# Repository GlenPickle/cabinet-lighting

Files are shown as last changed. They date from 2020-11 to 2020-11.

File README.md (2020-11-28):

Arduino controlled cabinet lighting with a Nextion Enhanced 3.2 inch TFT Display

## Design Description:

The Nextion screen allows the user to interface with the lights. A leader Arduino Pro Micro listens for instructions from the Nextion Interface over serial, and sends these instructions to a follower Arduino Pro Micro. The Leader/Follower design is used to prevent Nextion signals being missed while calling the blocking functions to change the color and brightness of the lights.

## Limitations:
In order for a Nextion callback function or Wire receiveEvent to update variables, they must be declared globally. This software and its Makefiles were made to be compiled on Linux. Windows compilation may be possible, but has not been tested.

## Screen Images:  
### The home screen:
  
### The color selection screen:

### The sliders to update brightness and speed:

### The settings screen:

### The Clock update screen. This is also used to set the times to turn off and on automatically:
  

## Light Images:
### Solid color choices:








### Pulse Effect:

### Alternating Effect

### Snake Effect

### Rainbow Effect

### Dance Party Effect


## How To Recreate:
### Software:
#### Dependencies:
* [Nextion Arduino Library](https://nextion.tech/resources/download/libraries/)
* [FastLED Library](https://github.com/FastLED/FastLED/releases)
* arduino-mk

#### Steps:
1. Install dependencies
2. Change the variable NUM_LEDS in libraries/ledInterface/led_interface.h to the number of LEDs that you plan to use
3. Compile LED interface by running `make` in the led_interface directory
4. Compile Screen interface by running `make` in the screen_interface directory
5. Upload the resulting sketch files to the arduinos following these [instructions](https://www.dummies.com/computers/arduino/how-to-upload-a-sketch-to-an-arduino/)
6. Use the [Nextion Editor](https://nextion.tech/nextion-editor/) to compile the HMI file into a Nextion .tft file
7. Upload the .tft to the Nextion following these [instructions](https://nextion.tech/faq-items/using-nextion-microsd/)

### Hardware
#### Hardware List:
1. Two [Arduino Pro Micros](https://www.sparkfun.com/products/12640) (cheaper clones available on Amazon)
2. One [Nextion 3.2 inch Enhanced Display](https://nextion.tech/datasheets/nx4024k032/) (available on Amazon)
3. A Five volt power supply with sufficient amperage. 256 LEDs use 15 Amps.
4. A strip of WS2812b LEDs
5. The file to have the wall plate laser cut is available in the Nextion Directory of this repo. I used Ponoko to have it made. It fits a low voltage double gang wall box.

Wire the power supply, Nextion Display, LED strip, and two Arduino Pro Micros according to the following circuit diagram:  
  
If running the LEDs across two sides of the room like I did, be careful not to leave more than 15 feet of wire between any two lights. This causes loss of data.

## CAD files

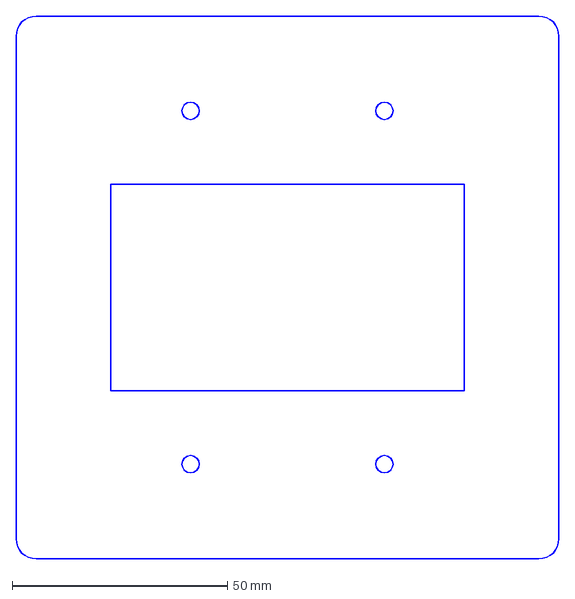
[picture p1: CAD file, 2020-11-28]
nextion/nextion_plate.dxf
126.0 x 126.0 mm

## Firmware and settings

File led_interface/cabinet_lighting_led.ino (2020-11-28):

/* Source code for the Under Cabinet Lighting. */
 
#include <Wire.h>
#include "FastLED.h"
#include "led_interface.h"

/************************** Begin Globals ************************************/
// The Arduino Wire library requires these vars to be global
ColorSettings    G_settings;
AlternatingPulse G_altPulse;
SnakePosition    G_snakePos;
Rainbow          G_rainbow;

// array for LEDs
CRGB         leds[NUM_LEDS];
/*************************** End Globals *************************************/


/******************************************************************************
**
**  Function Name: solidHSV
**
**  Purpose: Change the color of all lights to a single solid color
**
******************************************************************************/
void solidHSV(uint32_t H, uint32_t S, uint32_t V) {
    for (int i = 0; i < NUM_LEDS; i++)
    {
        leds[i] = CHSV(H, S, V);
    }
    FastLED.show();
}


/******************************************************************************
**
**  Function Name: showErrorLights
**
**  Purpose: To light up all the lights red when an error is detected
**
******************************************************************************/
void showErrorLights(ColorSettings *colorSettings)
{
    colorSettings->action = LED_SOLID;
    colorSettings->color = RED;
    colorSettings->currentColor.hue = 0;
    colorSettings->currentColor.sat = 255;
    colorSettings->currentColor.val = 127;
    solidHSV(colorSettings->currentColor.hue,
             colorSettings->currentColor.sat,
             colorSettings->currentColor.val);
}


/******************************************************************************
**
**  Function Name: updateLights
**
**  Purpose: If an animation is running, update to the next step
**
******************************************************************************/
void updateLights(ColorSettings *colorSettings, AlternatingPulse *altPulse,
                  SnakePosition *snakePos, Rainbow *rainbow)
{
    switch(colorSettings->action)
    {
        case LED_SOLID:
        case LED_OFF:
            break; // these cases need no updating, the color is set in the button callback

        case LED_PULSE:
            // For pulse we update by changing the brightness of all the lights by one step
            altPulse->dv = ((exp(sin(altPulse->pulseSpeed * millis()/2000.0*PI)) -0.36787944) * altPulse->delta);
            altPulse->altVal = altPulse->altValueMin + altPulse->dv;

            // Map altHue based on current altVal
            altPulse->altHue = map(altPulse->altVal, altPulse->altValueMin, altPulse->altValueMax,
                                   altPulse->altHueA, altPulse->altHueB);

            // Map altSat based on current altVal
            altPulse->altSat = map(altPulse->altVal, altPulse->altValueMin, altPulse->altValueMax,
                                   altPulse->altSatA, altPulse->altSatB);
    
            // for the "all" color selection we set each individual light it's own color and pulse to black
            for (uint32_t i = 0; i < NUM_LEDS; i++)
            {
                if (colorSettings->color == ALL)
                {
                    altPulse->altHue = i;
                }
                leds[i] = CHSV(altPulse->altHue, altPulse->altSat, altPulse->altVal);
            }
            FastLED.show();
            break;

        case LED_SNAKE:
            snakePos->tail = snakePos->tail++ % NUM_LEDS;
            snakePos->head = snakePos->tail + snakePos->quarter % NUM_LEDS;

            // For snake we update by lighting up one more light and turning off one at the beginning
            leds[snakePos->tail] = CRGB(0, 0, 0);
            if (colorSettings->color == ALL)
            {
                colorSettings->currentColor.hue = snakePos->head;
            }
            leds[snakePos->head] = CHSV(colorSettings->currentColor.hue,
                                        colorSettings->currentColor.sat,
                                        colorSettings->currentColor.val);
            FastLED.show();
            delay(colorSettings->delayTime);
            break;

        case LED_RAINBOW:
            // for rainbow we increment the hue of each light by one, rolling over to 0 if the hue is over 255
            for (uint32_t i = 0; i < NUM_LEDS; i++)
            {
                rainbow->hue = (rainbow->index + i > 255) ? rainbow->index + i - 255 : rainbow->index + i;
                leds[i] = CHSV(rainbow->hue, 255, colorSettings->currentColor.val);
            }
            rainbow->index++;
            FastLED.show();
            delay(colorSettings->delayTime);
            break;
    
        case LED_ALTERNATING:
            // for alternating we update by changing the altHue of all the lights by one step
            // if the color is all we just cycle through all colors
            if (colorSettings->color == ALL || colorSettings->color2 == ALL)
            {
                colorSettings->currentColor.hue++;
                if (colorSettings->currentColor.hue >= 255)
                {
                    colorSettings->currentColor.hue = 0;
                }
                solidHSV(colorSettings->currentColor.hue, 255, colorSettings->currentColor.val);
                delay(colorSettings->delayTime);
            }
            // otherwise we find a step between the two chosen colors, and change each light to this altHue
            else
            {
                // For pulse we update by changing the brightness of all the lights by one step
                altPulse->dv = ((exp(sin(altPulse->pulseSpeed * millis()/2000.0*PI)) -0.36787944) * altPulse->delta);
                altPulse->altVal = altPulse->altValueMin + altPulse->dv;

                // Map altHue based on current altVal
                altPulse->altHue = map(altPulse->altVal, altPulse->altValueMin, altPulse->altValueMax,
                                       altPulse->altHueA, altPulse->altHueB);

                // Map altSat based on current altVal
                altPulse->altSat = map(altPulse->altVal, altPulse->altValueMin, altPulse->altValueMax,
                                       altPulse->altSatA, altPulse->altSatB);

                solidHSV(altPulse->altHue, altPulse->altSat, altPulse->altVal);
            }
            break;

        case LED_DANCEPARTY:
            // for Dance Party we just go totally random for every light, with max brightness and saturation
            for (int i=0; i<NUM_LEDS; i++)
            {
                int h = random() % 256;
                leds[i] = CHSV(h, 255, 255);
            }
            FastLED.show();
            delay(colorSettings->delayTime);
            break;
    } 
}
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

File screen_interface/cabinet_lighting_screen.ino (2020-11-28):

/* Source code for the Under Cabinet Lighting. */
/* The sketch generated will run on the arduino connected to the TFT. */
#include <Wire.h>
#include "Nextion.h"
#include "screen_interface.h"

/***************************** BEGIN GLOBALS *********************************/
/* Note that in order for the nextion library to update variables they must be declared globally. */
// global variables for the light settings: action, color, brightness and speed
Settings G_settings;

// global variables for the auto on and off feature
Defaults G_defaults;

// Note, the Nextion Library expects all TFT objects to be defined globally
// The pointer for button clicks
NexGauge pointer  = NexGauge(0, 1, "pointer");

// The pages that the arduino will need access to
NexPage pAction           = NexPage(0, 0, "HomeScreen");
NexPage pColor            = NexPage(1, 0, "ColorScreen");
NexPage pBrightness       = NexPage(2, 0, "Brightness");
NexPage pSpeed            = NexPage(3, 0, "Speed");
NexPage pBrightnessSpeed  = NexPage(4, 0, "BrightSpeed");

// The buttons for the first page where mode is selected
NexButton bSolid    = NexButton(0, 2, "bSolid");
NexButton bPulse    = NexButton(0, 3, "bPulse");
NexButton bSnake    = NexButton(0, 4, "bSnake");
NexButton bAlt      = NexButton(0, 5, "bAlternating");
NexButton bRainbow  = NexButton(0, 6, "bRainbow");
NexButton bDance    = NexButton(0, 7, "bDance");
NexButton bOff      = NexButton(0, 8, "bOff");

// The buttons for the second page where colors are selected
NexButton bAll    = NexButton(1, 2, "bAll");
NexButton bGreen  = NexButton(1, 3, "bGreen");
NexButton bBlue   = NexButton(1, 4, "bBlue");
NexButton bPurple = NexButton(1, 5, "bPurple");
NexButton bWhite  = NexButton(1, 6, "bWhite");
NexButton bCyan   = NexButton(1, 7, "bCyan");

// The text for the second page where colors are selected
NexText tChoose = NexText(1, 9, "t0");

// The button for setting the default color settings
NexButton bSetDefaults = NexButton(9, 2, "bYes");

// The Slider for the page with just brightness
NexSlider hBrightness = NexSlider(2, 2, "hBrightness");

// The Slider for the page with just speed
NexSlider hSpeed = NexSlider(3, 2, "hSpeed");

// The sliders for the page with brightness and speed
NexSlider hBrightness2 = NexSlider(4, 2, "hBrightness");
NexSlider hSpeed2      = NexSlider(4, 6, "hSpeed");

// The buttons for the clock when auto times are set
NexButton b1 = NexButton(8, 4, "b1");
NexButton b2 = NexButton(8, 5, "b2");
NexButton b3 = NexButton(8, 6, "b3");
NexButton b4 = NexButton(8, 7, "b4");
NexButton b5 = NexButton(8, 8, "b5");
NexButton b6 = NexButton(8, 9, "b6");
NexButton b7 = NexButton(8, 10, "b7");
NexButton b8 = NexButton(8, 11, "b8");
NexButton b9 = NexButton(8, 12, "b9");
NexButton b0 = NexButton(8, 14, "b1");

// The Text for the auto on off clock
NexText tHour1   = NexText(8, 19, "t5");
NexText tHour2   = NexText(8, 18, "t4");
NexText tMinute1 = NexText(8, 17, "t3");
NexText tMinute2 = NexText(8, 16, "t2");

// The variable for whether we are updating turnOn or turnOff
NexVariable vOnOff = NexVariable(8, 24, "onOrOff");

// The RTC module
NexRtc rtc;

/******************************** END GLOBALS ********************************/

// This is the list that the Nextion lib uses to get serial input from the GUI
NexTouch *nex_listen_list[] = 
{
    &pAction,
    &pColor,
    &pBrightness,
    &pSpeed,
    &pBrightnessSpeed,
    &bSolid,
    &bPulse,
    &bSnake,
    &bAlt,
    &bRainbow,
    &bDance,
    &bOff,
    &bAll,
    &bGreen,
    &bBlue,
    &bPurple,
    &bWhite,
    &bCyan,
    &b1,
    &b2,
    &b3,
    &b4,
    &b5,
    &b6,
    &b7,
    &b8,
    &b9,
    &b0,
    &bSetDefaults,
    &hBrightness,
    &hSpeed,
    &hBrightness2,
    &hSpeed2,
    &vOnOff,
    NULL
};

/******************************************************************************
**
**  Function Name: showErrorLights
**
**  Purpose: To light up all the lights red when an error is detected
**
**  Globals Used: none
**
**  Globals Set: G_settings
**
******************************************************************************/
void showErrorLights()
{
    Settings *settings = &G_settings;
    settings->action = LED_SOLID;
    settings->color = RED;
    settings->haveUpdate = true;
}


/******************************************************************************
**
**  Function Name: buttonActionPopCallback
**
**  Purpose: To check which action button was pressed and decide if 
**           the LEDs need instruction
**
**  Globals Used: none
**
**  Globals Set: G_settings
**
******************************************************************************/
void buttonActionPopCallback(void *ptr)
{
    Settings *settings = &G_settings;
    NexButton *button = (NexButton *) ptr;
    char buffer[100] = {0};

    if (button->getText(buffer, sizeof(buffer)) <= 0)
    {
        showErrorLights();
        return;
    }

    if (strcmp(buffer, "Solid Color") == 0)
    {
        settings->action = LED_SOLID;
        pColor.show();
        return;
    }
    else if (strcmp(buffer, "Pulse") == 0)
    {
        settings->action = LED_PULSE;
        pColor.show();
        return;
    }
    else if (strcmp(buffer, "Snake") == 0)
    {
        settings->action = LED_SNAKE;
        pColor.show();
        return;
    }
    else if (strcmp(buffer, "Alternating") == 0)
    {
        settings->action = LED_ALTERNATING;
        pColor.show();
        return;
    }
    else if (strcmp(buffer, "Rainbow") == 0)
    {
        settings->action = LED_RAINBOW;
        settings->haveUpdate = true; // no color selection, go ahead and update

        // set brightness and speed to defaults
        settings->brightnessPosition = 127;
        settings->speedPosition = 50;
        pBrightnessSpeed.show();
        return;
    }
    else if (strcmp(buffer, "Dance Party") == 0)
    {
        settings->action = LED_DANCEPARTY;
        settings->haveUpdate = true; // no color selection, go ahead and update

        // set brightness and speed to defaults
        settings->brightnessPosition = 127;
        settings->speedPosition = 50;
        pBrightnessSpeed.show();
        return;
    }
    else if (strcmp(buffer, "Off") == 0)
    {
        settings->action = LED_OFF;
        settings->haveUpdate = true; // no color selection for Off, update now

        // set brightness and speed to defaults
        settings->brightnessPosition = 127;
        settings->speedPosition = 50;
        return;
    }
    else
    {
        // unexpected value, error and return
        showErrorLights();
        return;
    }
}
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
